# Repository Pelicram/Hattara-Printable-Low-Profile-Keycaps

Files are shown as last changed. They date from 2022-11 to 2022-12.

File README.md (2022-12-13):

# Hattara Printable Low Profile Keycaps



3D Printable Low Profile MX/Choc V1 Keycaps, designed to be printed with SLS, MJF or resin printers on sites like JLCPCB and PCBWay. The tolerances have been tested to work with SLS and MJF.

## Versions

* Choc V1 keycaps with Choc Spacing (prefix "Choc-cs" in filenames, 17.45 x 16.45mm)
* Choc V1 keycaps with MX Spacing (prefix "Choc-mxs" in filenames, 17.9 x 17.9mm)
* MX keycaps (prefix "MX" in filenames, 17.9 x 17.9mm, 0.5mm taller than Choc caps)

All keyboards that support both Choc and MX switches are designed with MX spacing. Most keyboards that only support Choc switches are designed with Choc spacing, but always check as there are exceptions. If you want to play it safe, get Choc spacing keycaps. They'll fit on MX spacing boards too but will leave bigger gaps between keys.

## Included sizes

* 1u
* 1.25u
* 1.5u
* ISO Enter
* Homing keys (6 variants)

1.75u, 2u, 2.25u and 2.75u keycaps coming Soon™.

## Please note

* Try to only insert the MX caps one way (sprue gate facing to the rear). Inserting them sideways may loosen them due to the asymmetry of some switch stems. If a keycap has been loosened it will need to be used in the sideways position from that point onward. The profile is uniform so this will only affect the position of the sprue gate but still something to keep in mind.

* Choc keycaps with Choc spacing don't include an ISO enter keycap as they're completely unstandardized. The MX spacing Choc ISO enter will fit on boards like PRKL30 that have MX spacing and a sideways enter switch.

* Choc caps don't include stabilizer stems.

* The files include individual caps as well as sprues. I highly recommend using the sprues as this ensures the parts meet the common minimum price per part on sites like JLCPCB, at least for SLS and MJF.

* JLCPCB accepts both .obj and .stp, but in my experience .obj results in higher fidelity due to how they convert .stp files into meshes. The .stp files are included mostly for remix purposes.

* The automatic file checker on JLC/etc will probably complain about 0.8mm thin walls, just say you're ok with it. From my testing it has no effect on print quality.

## Version Renders

Choc keycaps with MX Spacing vs Choc Spacing       |  MX vs Choc keycaps
:-------------------------:|:-------------------------:
  | 

## Sprue Renders

all            |  1u-sprue
:-------------------------:|:-------------------------:
 |  
1_25u-sprue  | 1_5u-sprue
 |  
homing-bars-sprue | homing-scoops-sprue
 |  
homing-dots-sprue | iso-sprue
 | 

## Examples

**Comparison between SLS and MJF Nylon prints.**

SLS has a more pronounced texture, and feels almost like sandstone. MJF has a smoother finish and is closer to textured PBT plastic. MJF is darker (when you pick the `Dyed Black` option, not sure about the non-dyed stuff). Dimensional accuracy is excellent for both and the tolerances required are identical.
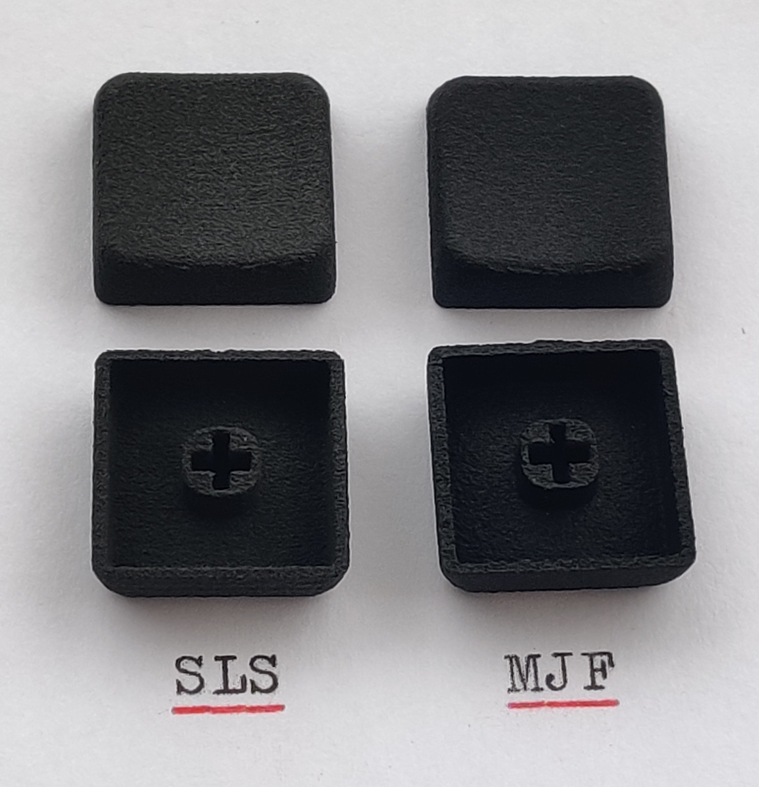
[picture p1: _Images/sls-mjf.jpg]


---

Keycaps shown below have been printed in Nylon on an SLS printer by JLCPCB.

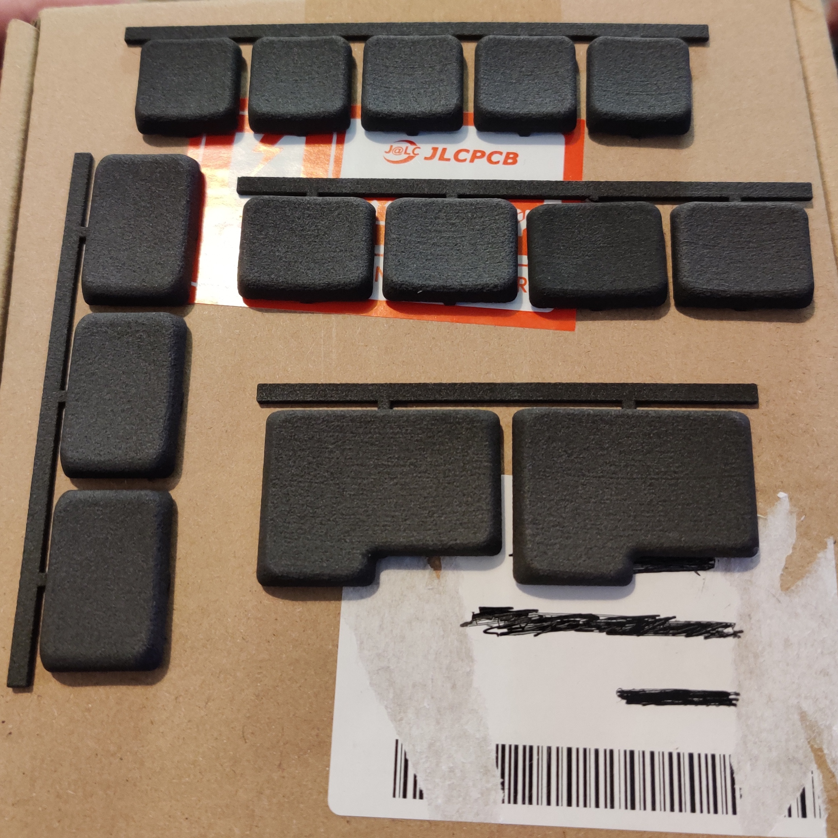
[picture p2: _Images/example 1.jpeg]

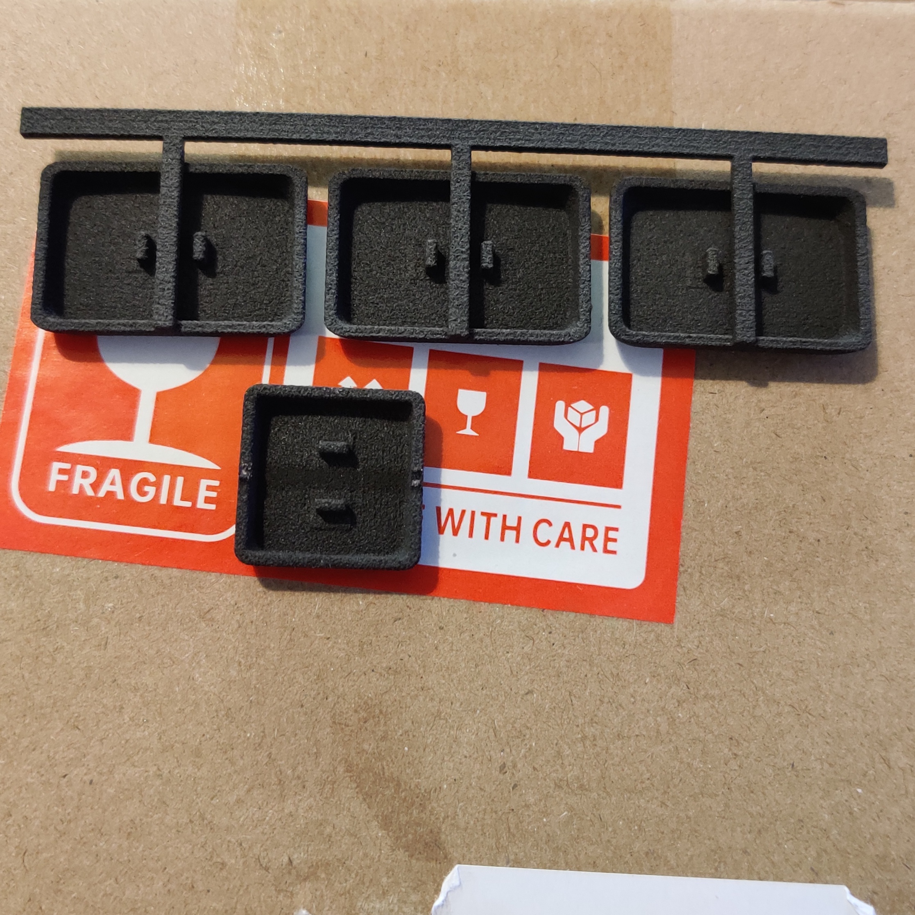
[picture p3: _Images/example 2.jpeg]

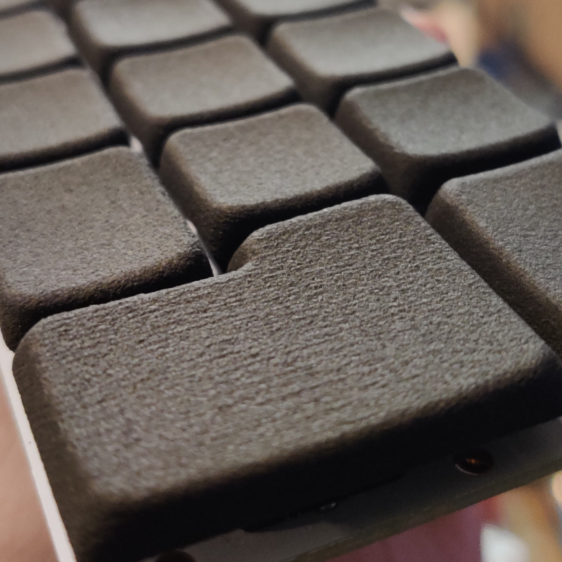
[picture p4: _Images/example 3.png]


---

_Licenced under [The TAPR Open Hardware License](https://tapr.org/the-tapr-open-hardware-license/)_

<a href="https://www.paypal.com/donate/?hosted_button_id=LNPV4WR7C95VA">Donate button</a>

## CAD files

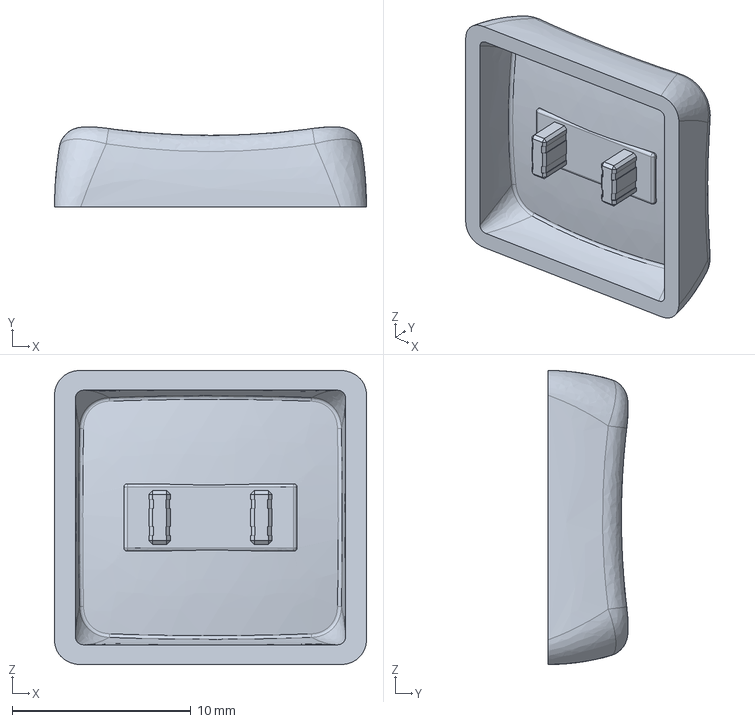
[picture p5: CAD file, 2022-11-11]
Choc Keycaps/Choc Spacing/STEP/Raw Caps/Choc-cs-1u.step
17.5 x 4.50 x 16.5 mm

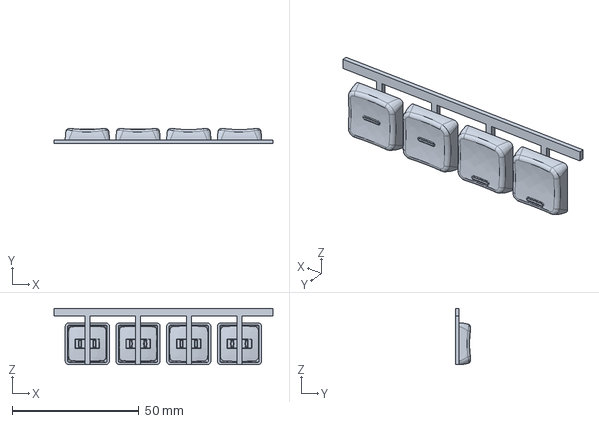
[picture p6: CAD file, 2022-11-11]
Choc Keycaps/Choc Spacing/STEP/Sprues/Choc-cs-homing-bars-sprue.step
86.4 x 5.99 x 22.2 mm

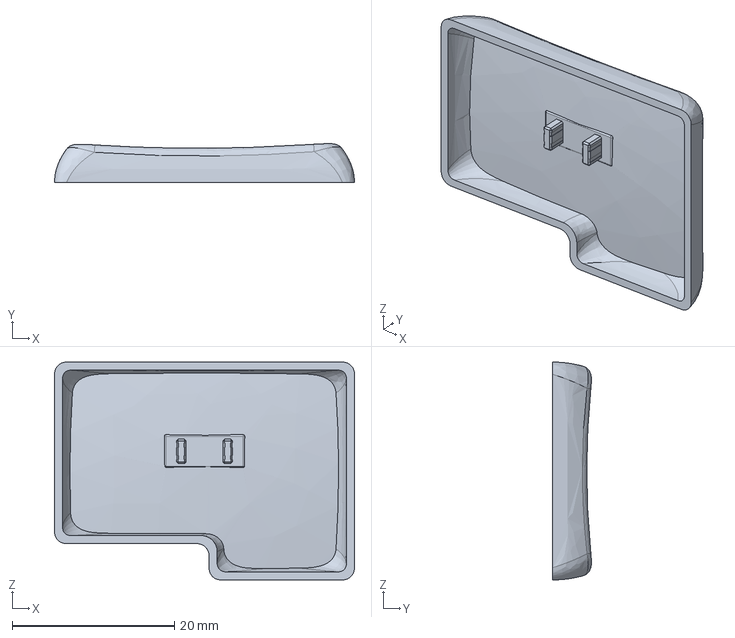
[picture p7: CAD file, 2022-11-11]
Choc Keycaps/MX Spacing/STEP/Raw Caps/Choc-mxs-iso.step
37.0 x 4.77 x 26.9 mm

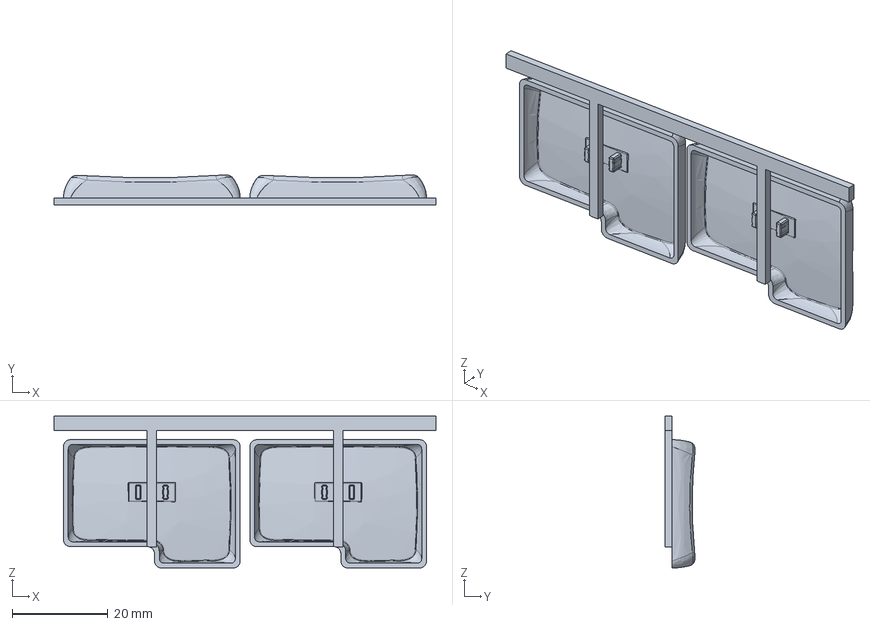
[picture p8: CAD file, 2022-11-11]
Choc Keycaps/MX Spacing/STEP/Sprues/Choc-mxs-iso-sprue.step
79.9 x 6.27 x 31.8 mm

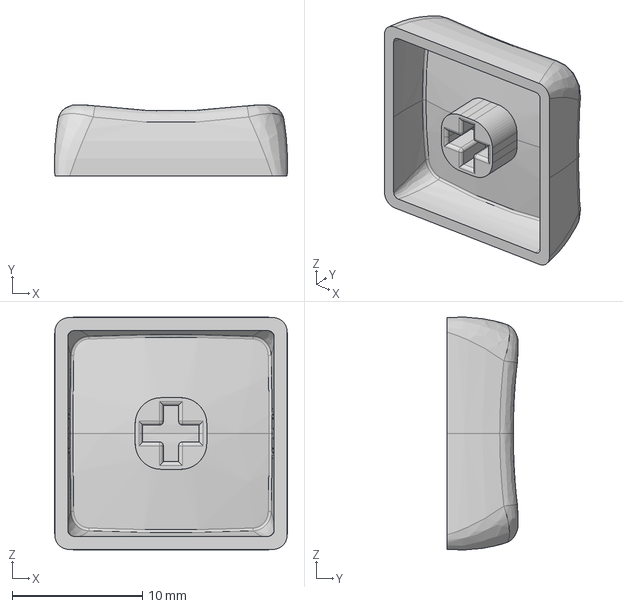
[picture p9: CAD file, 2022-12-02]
MX Keycaps/STEP/Raw Caps/MX-homing-bar-center.step
17.9 x 5.48 x 17.9 mm

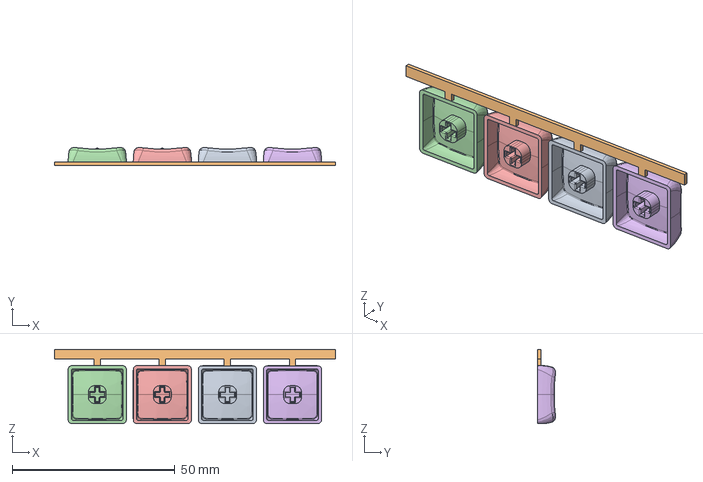
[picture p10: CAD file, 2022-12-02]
MX Keycaps/STEP/Sprues/MX-homing-bumps-sprue.step
86.4 x 5.48 x 22.9 mm

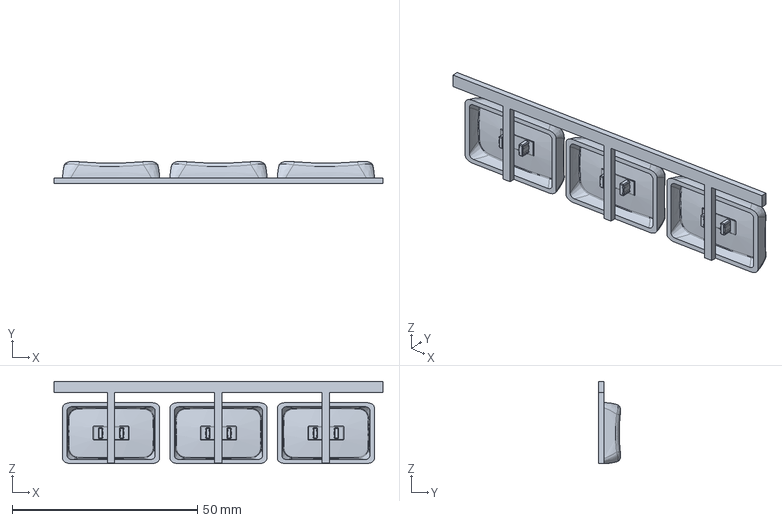
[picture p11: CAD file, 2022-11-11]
Choc Keycaps/Choc Spacing/STEP/Sprues/Choc-cs-1_5u-sprue.step
88.8 x 6.00 x 22.2 mm

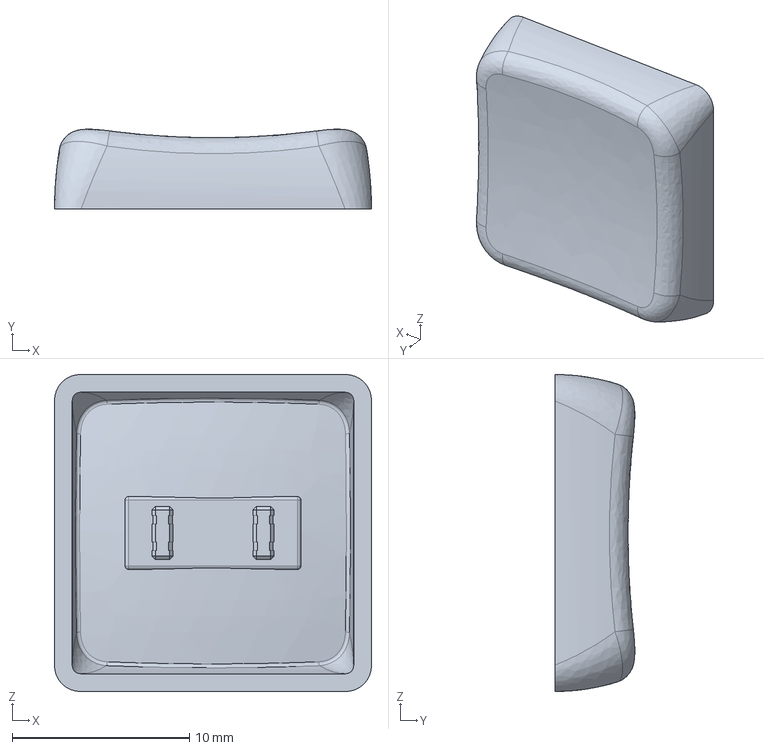
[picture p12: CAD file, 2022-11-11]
Choc Keycaps/MX Spacing/STEP/Raw Caps/Choc-mxs-1u.step
17.9 x 4.50 x 17.9 mm

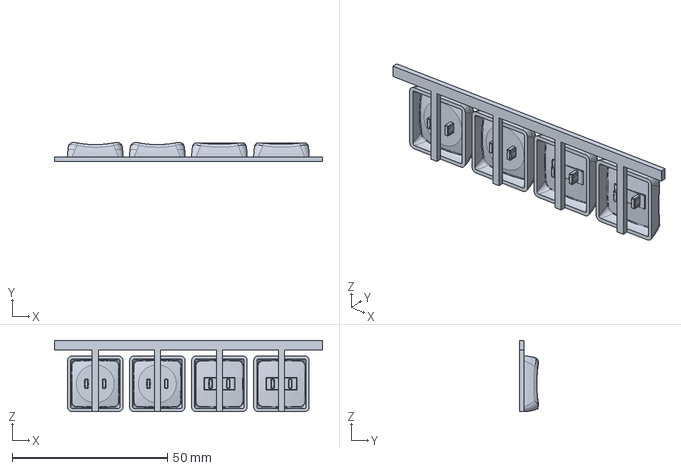
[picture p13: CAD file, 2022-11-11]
Choc Keycaps/MX Spacing/STEP/Sprues/Choc-mxs-homing-scoops-sprue.step
86.4 x 6.12 x 22.9 mm

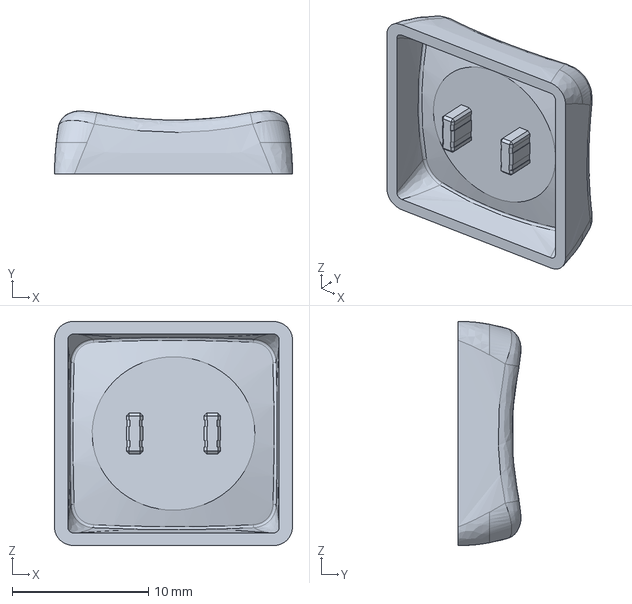
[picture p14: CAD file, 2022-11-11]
Choc Keycaps/Choc Spacing/STEP/Raw Caps/Choc-cs-homing-scoop-classic.step
17.5 x 4.62 x 16.5 mm

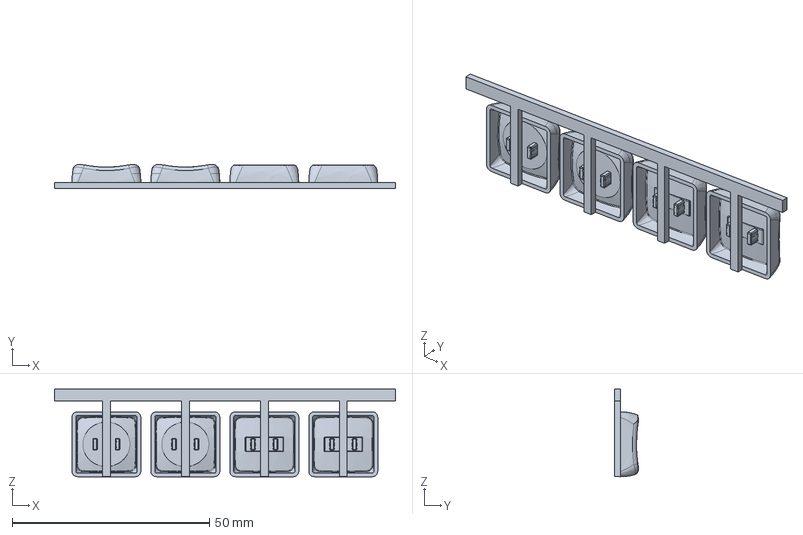
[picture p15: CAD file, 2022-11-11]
Choc Keycaps/Choc Spacing/STEP/Sprues/Choc-cs-homing-scoops-sprue.step
86.4 x 6.12 x 22.2 mm

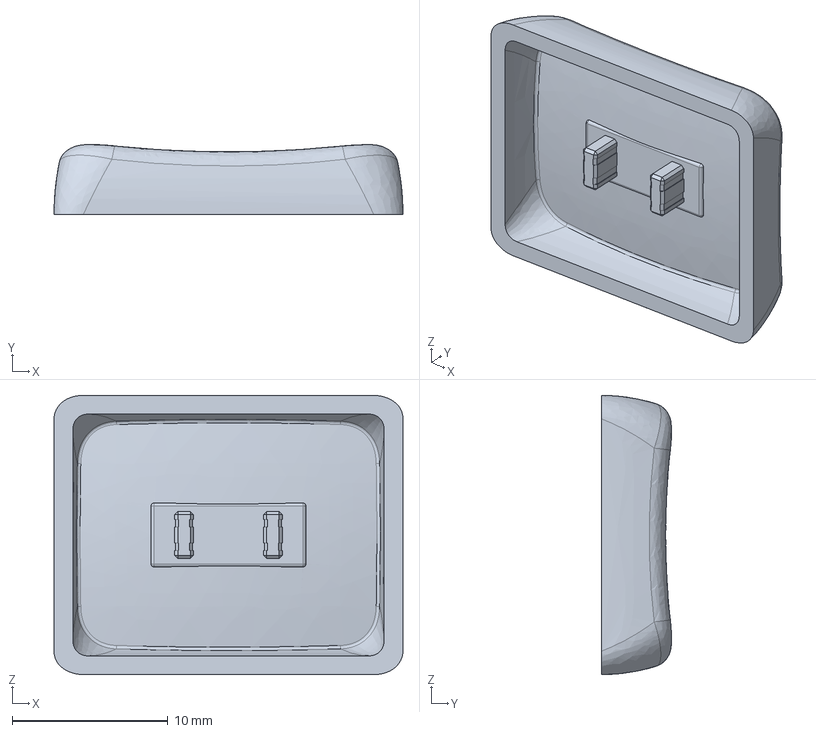
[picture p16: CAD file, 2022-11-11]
Choc Keycaps/MX Spacing/STEP/Raw Caps/Choc-mxs-1_25u.step
22.4 x 4.50 x 17.9 mm

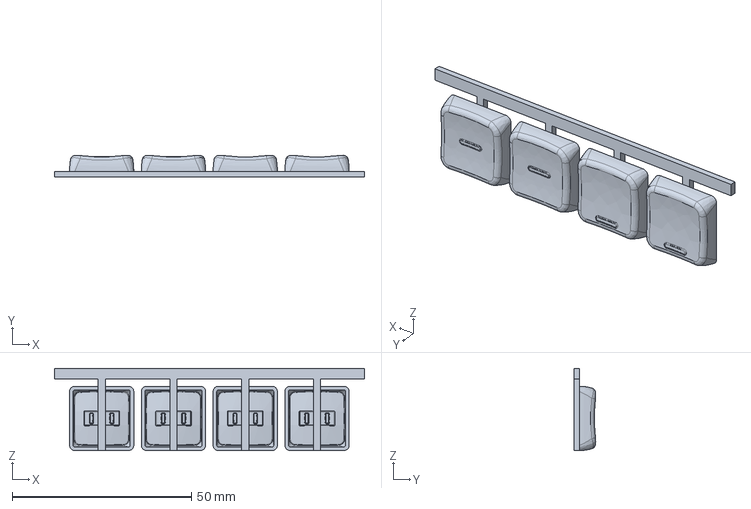
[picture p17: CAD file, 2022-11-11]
Choc Keycaps/MX Spacing/STEP/Sprues/Choc-mxs-homing-bars-sprue.step
86.4 x 5.99 x 22.9 mm

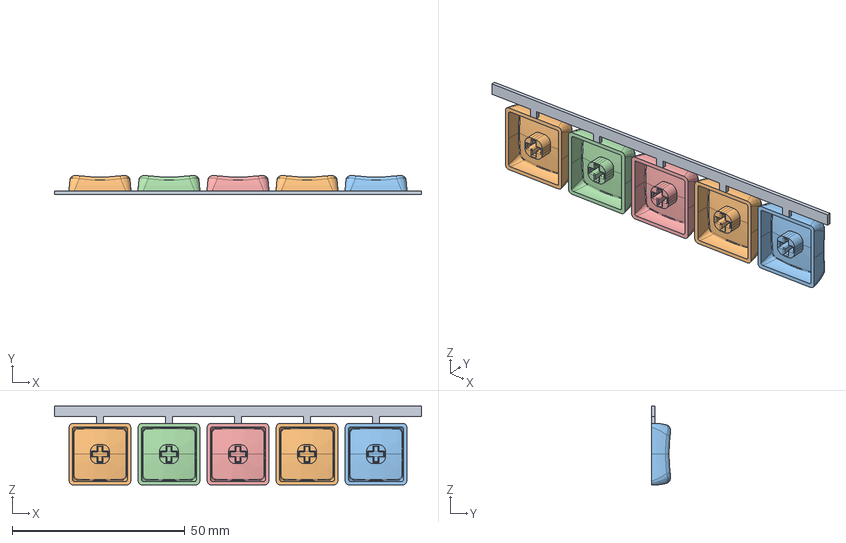
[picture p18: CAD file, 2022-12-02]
MX Keycaps/STEP/Sprues/MX-1u-sprue.step
106.4 x 5.48 x 22.9 mm

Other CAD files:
Choc Keycaps/Choc Spacing/STEP/Raw Caps/Choc-cs-homing-bump-bottom.step
MX Keycaps/STEP/Raw Caps/MX-homing-bar-bottom.step
MX Keycaps/STEP/Sprues/MX-homing-bars-sprue.step
MX Keycaps/STEP/Raw Caps/MX-homing-bump-center.step
Choc Keycaps/Choc Spacing/OBJ/Raw Caps/Choc-cs-1_25u.obj
Choc Keycaps/Choc Spacing/OBJ/Raw Caps/Choc-cs-1_5u.obj
Choc Keycaps/Choc Spacing/OBJ/Raw Caps/Choc-cs-homing-bar-center.obj
Choc Keycaps/Choc Spacing/OBJ/Raw Caps/Choc-cs-homing-scoop-classic.obj
Choc Keycaps/Choc Spacing/OBJ/Raw Caps/Choc-cs-homing-scoop-ridge.obj
Choc Keycaps/Choc Spacing/STEP/Raw Caps/Choc-cs-1_25u.step
Choc Keycaps/Choc Spacing/STEP/Raw Caps/Choc-cs-1_5u.step
Choc Keycaps/Choc Spacing/STEP/Raw Caps/Choc-cs-homing-bar-bottom.step
Choc Keycaps/Choc Spacing/STEP/Raw Caps/Choc-cs-homing-bar-center.step
Choc Keycaps/Choc Spacing/STEP/Raw Caps/Choc-cs-homing-bump-center.step
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

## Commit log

2022-10-25 Added homing keys
2022-10-25 Update README.md
    Added homing keys to size list.
2022-10-25 Update README.md
    Updated homing key info
    Added renders
2022-11-11 Restructure and Update
    Restructured into folders
    Added Choc Keycaps with Choc Spacing
    Added MX Keycaps
    Added Images folder
    Redone Renders
    Updated Readme
    [1_25u-sprue.step, 1_25u.step, 1_5u-sprue.step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]
2022-11-22 Update README.md
    Add note about mx insertion direction
    Improve formatting
2022-12-02 Small fix to 1u mx caps
    Fixed mx 1u caps and some homing keys not being completely symmetrical
    [MX-1u-sprue.step, MX-1u.step, MX-homing-bar-bottom.step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]
2022-12-12 Update Readme
    Added comparison between SLS and MJF prints.

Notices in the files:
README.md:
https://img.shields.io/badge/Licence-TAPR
